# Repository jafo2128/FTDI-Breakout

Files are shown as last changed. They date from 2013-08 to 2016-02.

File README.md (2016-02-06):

# FTDI-Breakout
The FTDI-Breakout is an USB to Serial Adapter with FTDI Chipset.

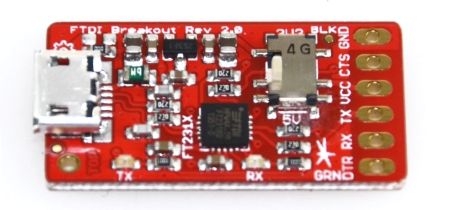
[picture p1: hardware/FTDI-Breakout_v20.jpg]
FTDI-Breakout (http://www.watterott.com/en/FTDI-Breakout-Reloaded-V2)


## Shop
* [FTDI FT231X Breakout](http://www.watterott.com/en/FTDI-Breakout-Reloaded-V2) (with soldered pin headers)
* [FTDI FT231X Breakout Light](http://www.watterott.com/en/FTDI-Breakout-Reloaded-V2-Light)

## Features
* USB UART Chipset: [FTDI FT231X](http://www.ftdichip.com/Products/ICs/FT231X.html) (v2) or [FTDI FT232R](http://www.ftdichip.com/Products/ICs/FT232R.htm) (v1)
* 3.3V or 5V logic/supply voltage selectable by switch
* Rx + Tx Status LEDs
* Overcurrent protection (resettable polyswitch fuse)
* Standard 6 pin FTDI connector with GND, CTS, VCC, TX, RX, DTR
* USB-Connector: microUSB (v2) or miniUSB (v1)

## Hardware and Software
* [Schematics + Layout](https://github.com/watterott/FTDI-Breakout/tree/master/hardware)
* [FTDI Serial Port Driver](http://www.ftdichip.com/Drivers/VCP.htm)

Finally words from us Archivers and Developers.. 

##### Donate

People from time to time wish to donate a little money. Donating won't get you anything special, other than a warm feeling inside, and possibly urge me to produce more freely available material for interesting projects. You can donate via [PayPal](https://www.paypal.com), just click [donate](https://www.paypal.com/cgi-bin/webscr?cmd=_s-xclick&hosted_button_id=3PXVSLXFBS45E) button available below - it will redirect you to the secured PayPal page where you can provide donation amount (there is no minimal value). Any donations are apreciated greatly, and we thank you all in advance for your support along the ways..



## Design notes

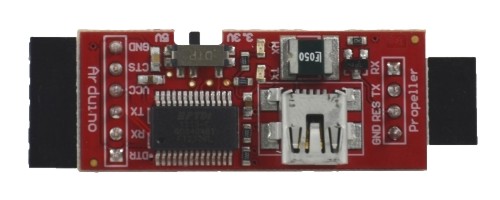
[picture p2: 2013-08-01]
hardware/FTDI-Breakout_v12.jpg

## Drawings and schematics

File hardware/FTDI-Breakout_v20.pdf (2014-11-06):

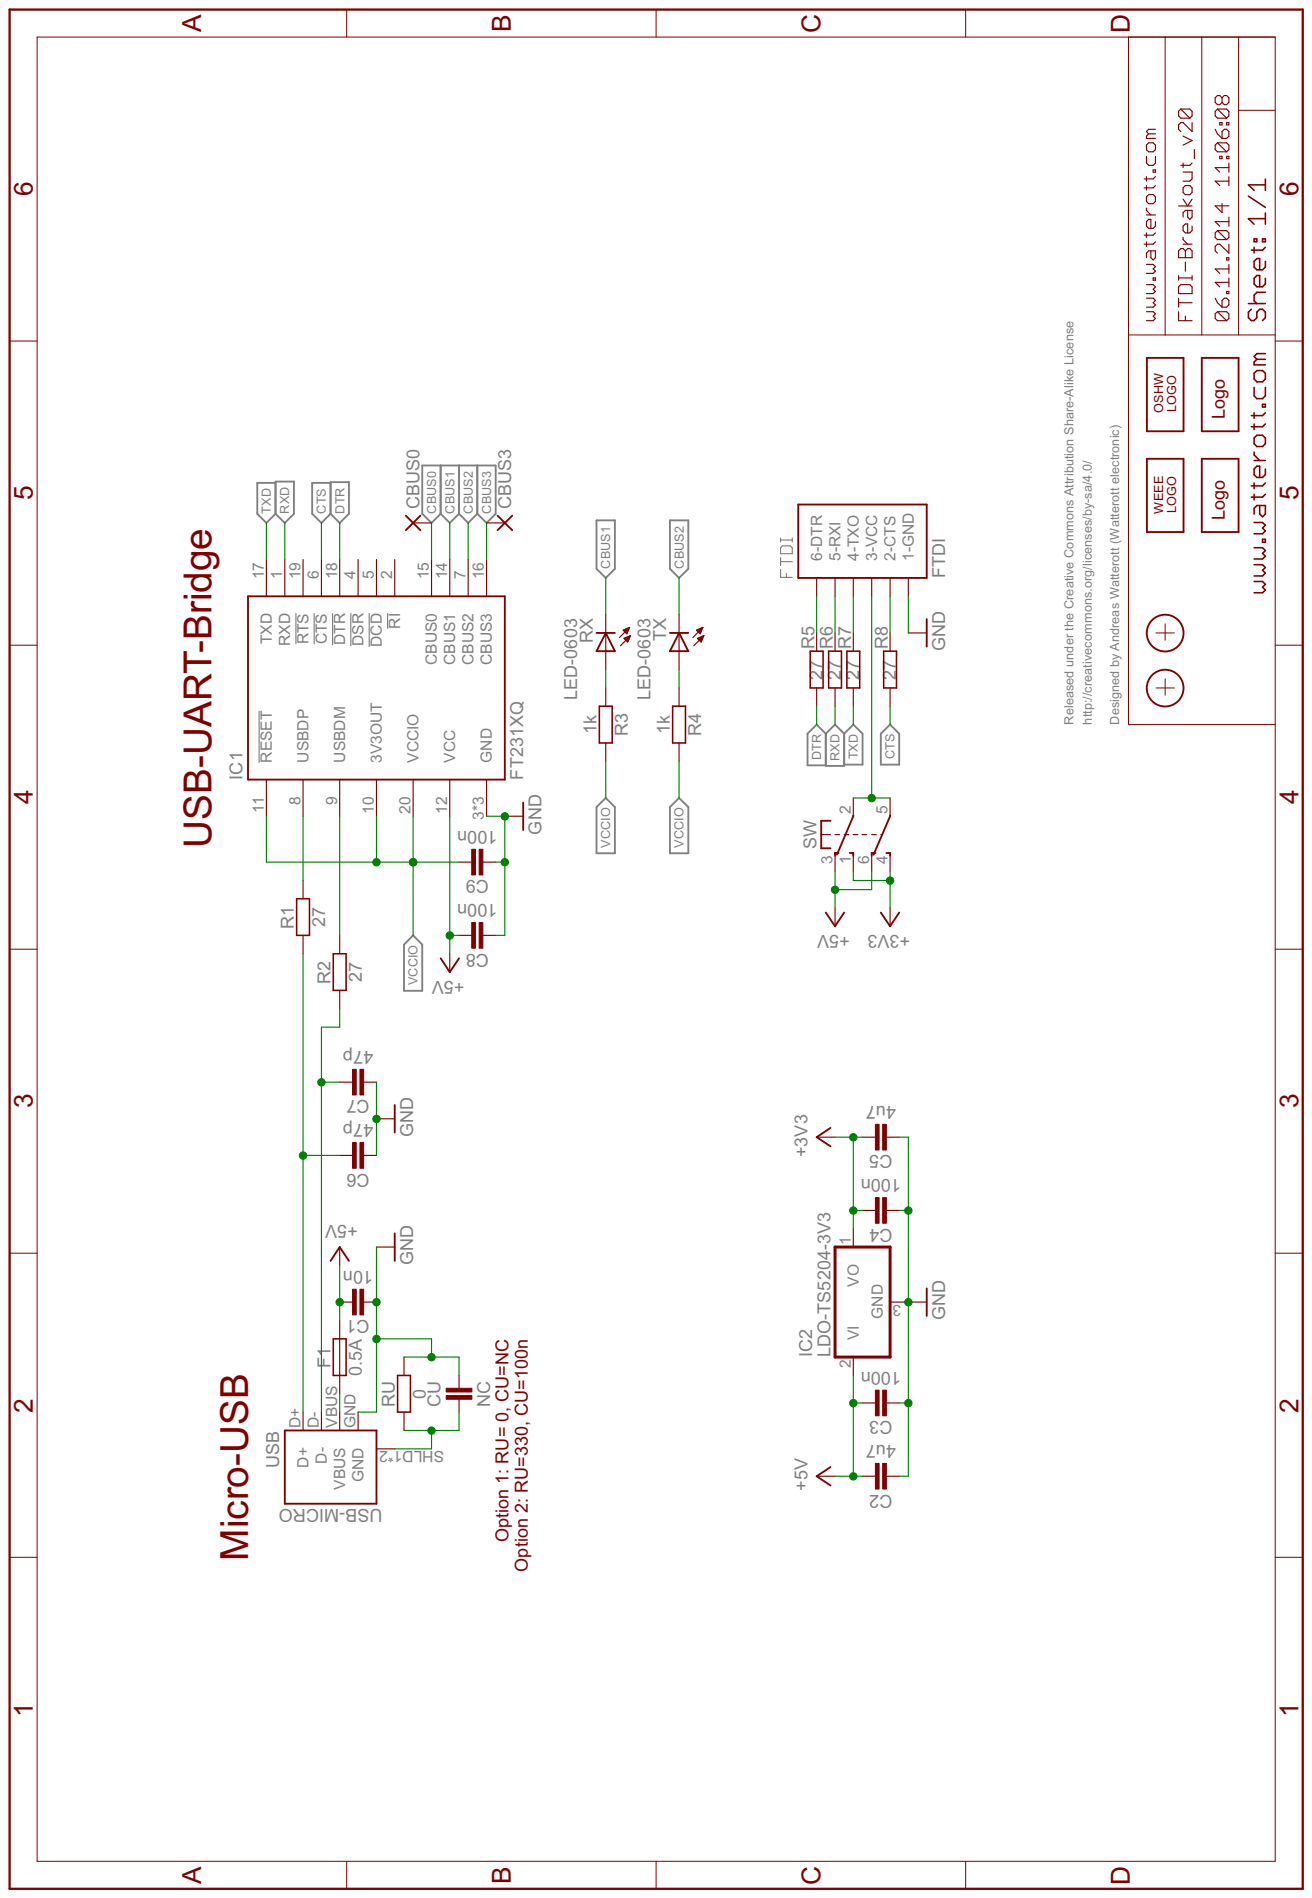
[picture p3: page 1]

FT231XQ LDO-TS5204-3V3 0.5A V5+ GND GND V5+ GND +3V3 +5V 27272727 GND V5+ 3V3+ n001 n001 7u4 27 27 n01 N0C LED-0603 1k LED-0603 1k n001 n001 7u4 p74 p74 GND Released under the Creative Commons Attribution Share-Alike License http://creativecommons.org/licenses/by-sa/4.0/ Designed by Andreas Watterott (Watterott electronic) IC13V3OUT 10 USBDM 9 USBDP 8 RESET 11 GND 3*3 TXD 17 RXD 1 RTS 19 CTS 6 DTR 18 DSR 4 DCD 5 RI 2 CBUS0 15 VCCIO 20 VCC 12 CBUS1 14 CBUS2 7 CBUS3 16 IC2 GND VI 2 3 VO 1 F1 D+ D+ D- D- VBUS VBUS GND GND USB ORCI M- BSU2* 1DLHS FTDI 6-DTR 5-RXI 4-TXO 3-VCC 2-CTS 1-GND 2 31 SW 5 64 R5R6R7R8 3C4C5C R1 R2 1C CURU RX R3 TX R4 8C9C 2C CBUS0 CBUS3 6C7C VCCIO VCCIO VCCIO CTS CTS DTR DTR CBUS0 CBUS1 CBUS1 CBUS2 CBUS2 CBUS3 TXD TXD RXD RXD Option 1: RU= 0, CU=NC Option 2: RU=330, CU=100n USB-UART-Bridge Micro-USB ABCD 1 2 3 4 5 6 ABCD 1 2 3 4 5 6 OSHW LOGO WEEE LOGO Logo Logo

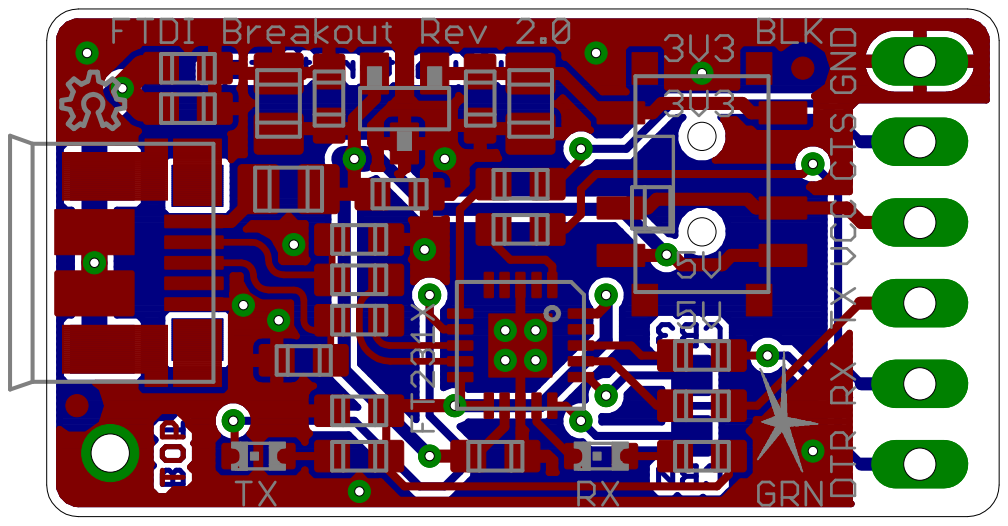
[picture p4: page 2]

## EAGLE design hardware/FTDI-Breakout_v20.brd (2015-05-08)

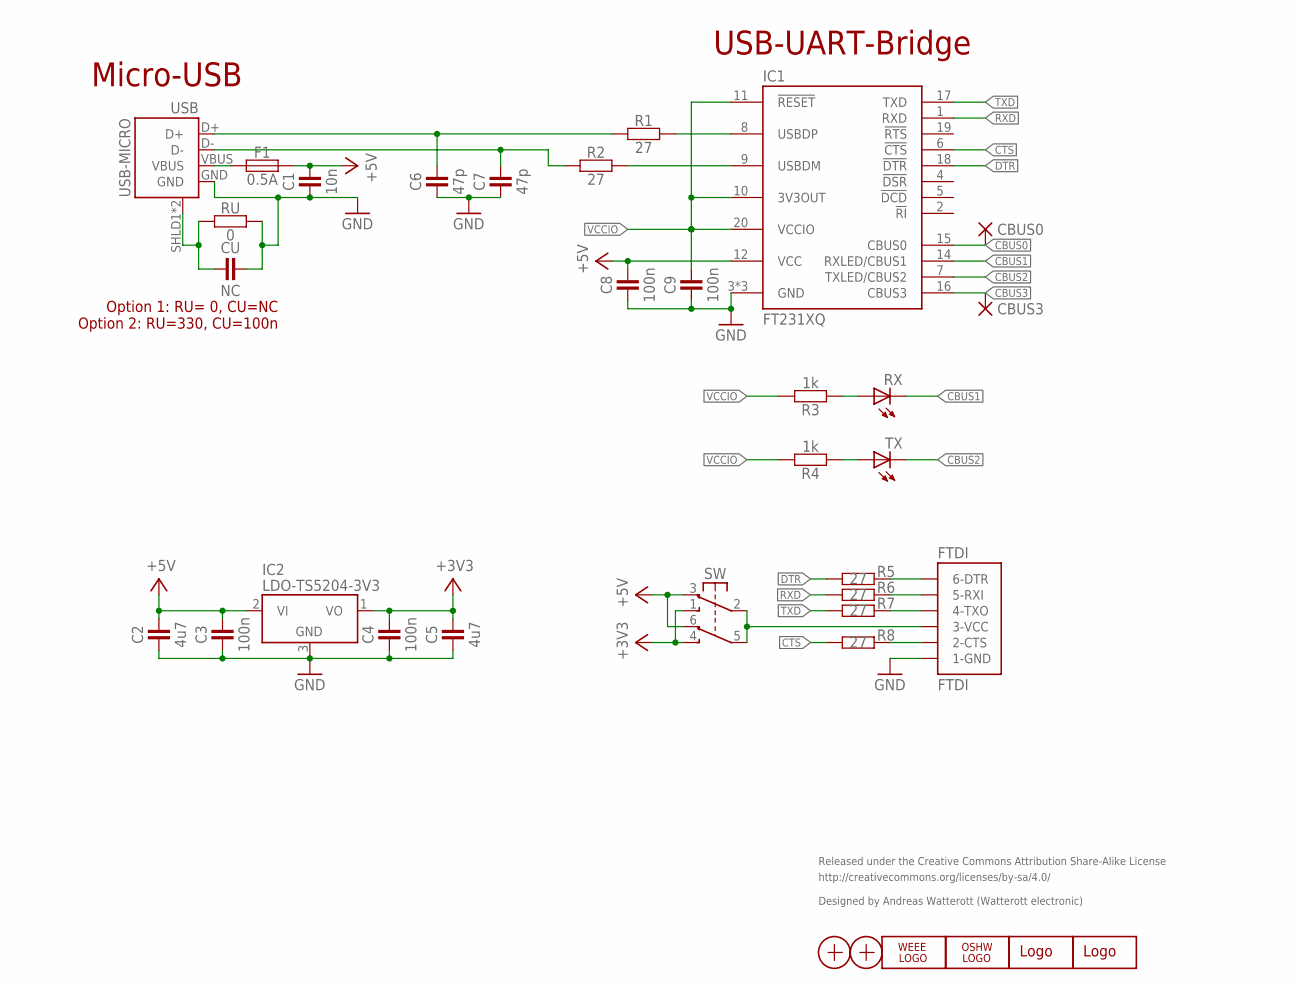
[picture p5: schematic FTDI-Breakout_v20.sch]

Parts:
C1: 10n; C0603
C2, C5: 4u7; C0805
C3, C4, C8, C9: 100n; C0603
C6, C7: 47p; C0603
CBUS0, CBUS3: PAD-1.27X1.27_NC
CU: NC; C0603
F1: 0.5A; C0805
FTDI: FTDI
IC1: FT231XQ; QFN20-PAD
IC2: LDO-TS5204-3V3; SOT23
LOGO1: WEEE_LOGO-S; WEEE_TPLAC_S
LOGO2: OSHW_LOGOX0070; OSHW_6X70
LOGO3: LOGO-S_PLACE_S; SPARK_TPLACE_S
LOGO4: LOGO-S_PLACE_M; SPARK_TPLACE_M
R1, R2, R5, R6, R7, R8: 27; C0603
R3, R4: 1k; C0603
RU: 0; C0603
RX: LED-0603; C0603
SW: SW-2UM-CUS22B; SW_CUS22B
TX: LED-0603; C0603
USB: USB-MICRO; USB-MICRO-10103594
X1, X2: PASSER-07; PASSER_07MM

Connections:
+3V3: C4.2, C5.2, IC2.1 (VO), SW.1 (S1), SW.4 (S2)
+5V: C1.2, C2.2, C3.2, C8.2, F1.2, IC1.12 (VCC), IC2.2 (VI), SW.3 (O1), SW.6 (O2)
CBUS0: CBUS0.1, IC1.15 (CBUS0)
CBUS1: IC1.14 (RXLED/CBUS1), RX.C
CBUS2: IC1.7 (TXLED/CBUS2), TX.C
CBUS3: CBUS3.1, IC1.16 (CBUS3)
CTS: IC1.6 (!CTS), R8.1
D2_N: IC1.9 (USBDM), R2.2
D2_P: IC1.8 (USBDP), R1.2
DTR: IC1.18 (!DTR), R5.1
D_N: C7.2, R2.1, USB.D-
D_P: C6.2, R1.1, USB.D+
FTDI-CTS: FTDI.2-CTS, R8.2
FTDI-DTR: FTDI.6-DTR, R5.2
FTDI-RXI: FTDI.5-RX (5-RXI), R6.2
FTDI-TXO: FTDI.4-TX (4-TXO), R7.2
FTDI-VCC: FTDI.3-VCC, SW.2 (P1), SW.5 (P2)
GND: C1.1, C2.1, C3.1, C4.1, C5.1, C6.1, C7.1, C8.1, C9.1, CU.2, FTDI.1-GND, IC1.3 (GND), IC1.13 (GND), IC1.TP (GND), IC2.3 (GND), RU.2, USB.GND
unnamed: CU.1, RU.1, USB.SHLD1 (SHIELD), USB.SHLD2 (SHIELD)
RX-LED: R3.1, RX.A
RXD: IC1.1 (RXD), R6.1
TX-LED: R4.1, TX.A
TXD: IC1.17 (TXD), R7.1
VBUS: F1.1, USB.VBUS
VCCIO: C9.2, IC1.10 (3V3OUT), IC1.11 (!RESET), IC1.20 (VCCIO), R3.2, R4.2

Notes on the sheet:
Released under the Creative Commons Attribution Share-Alike License
http://creativecommons.org/licenses/by-sa/4.0/
Designed by Andreas Watterott (Watterott electronic)
Option 1: RU= 0, CU=NC Option 2: RU=330, CU=100n
USB-UART-Bridge
Micro-USB

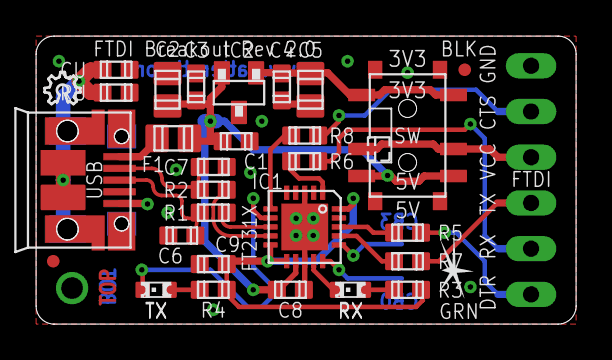
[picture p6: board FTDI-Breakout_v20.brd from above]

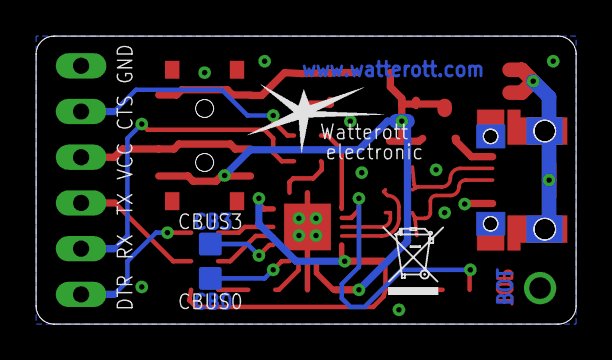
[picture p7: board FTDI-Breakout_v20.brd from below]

Board: 2 copper layers, 30.0 x 16.0 mm, 35 parts (4 on the bottom side), 25 nets.

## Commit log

2013-08-01 updated pcb
2014-11-06 added v2 layout and schematics
    [FTDI-Breakout_v20.brd, FTDI-Breakout_v20.sch]
2014-11-06 updated schematics and layout
    [FTDI-Breakout_v20.brd, FTDI-Breakout_v20.sch]
2014-12-12 cleaned up schematics and layout
    [FTDI-Breakout_v20.sch]
2015-05-08 updated layout and schematics
    [FTDI-Breakout_v20.brd, FTDI-Breakout_v20.sch]
2015-08-21 changed path structure
    [FTDI-Breakout_v20.brd, FTDI-Breakout_v20.sch]
